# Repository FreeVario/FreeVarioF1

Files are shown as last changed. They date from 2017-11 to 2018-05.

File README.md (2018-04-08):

## Welcome to FreeVario

Freevario is an opensource device to provides telemetry data to any vario based program such as XCSoar or XCTrack via bluetooth or wifi. It is based on de STM32F3 processor. The project includes the board Eagle design and source code.
The current status of the project is beta, it is 100% usable, just some rough edges here and there. Since the paragliding season is active, only bug fixes will be added. 

  <p > 
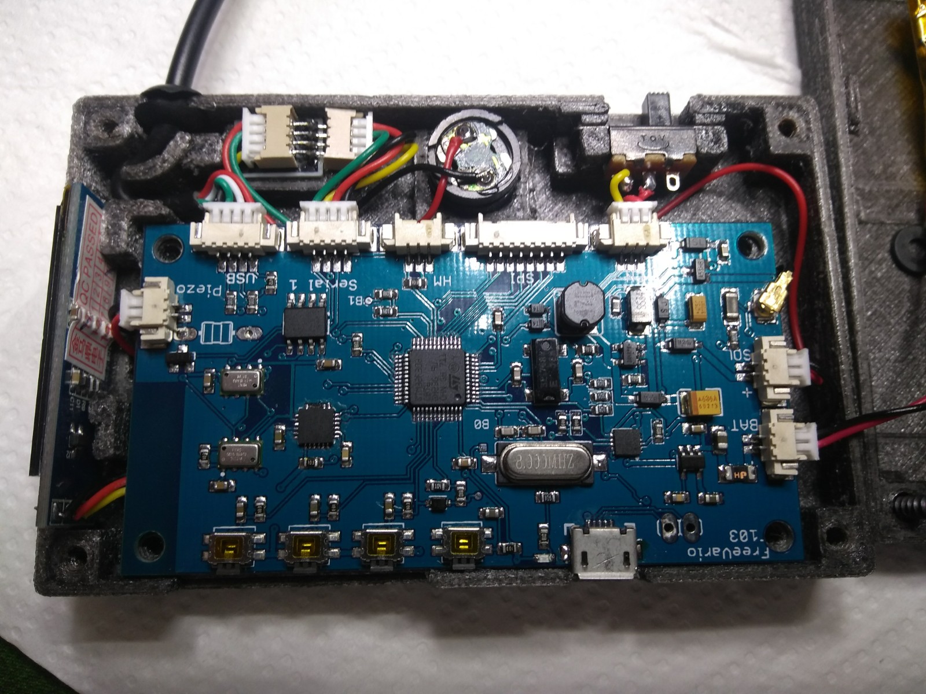
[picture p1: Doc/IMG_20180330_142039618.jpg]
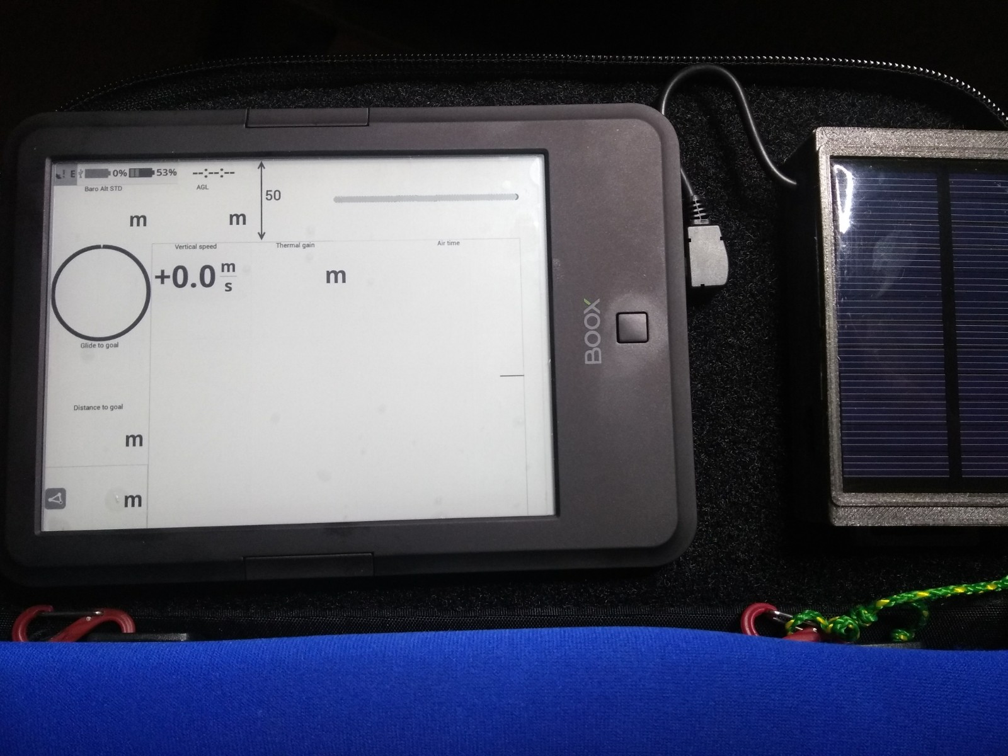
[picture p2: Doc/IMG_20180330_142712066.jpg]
     
  </p>
  <p > 
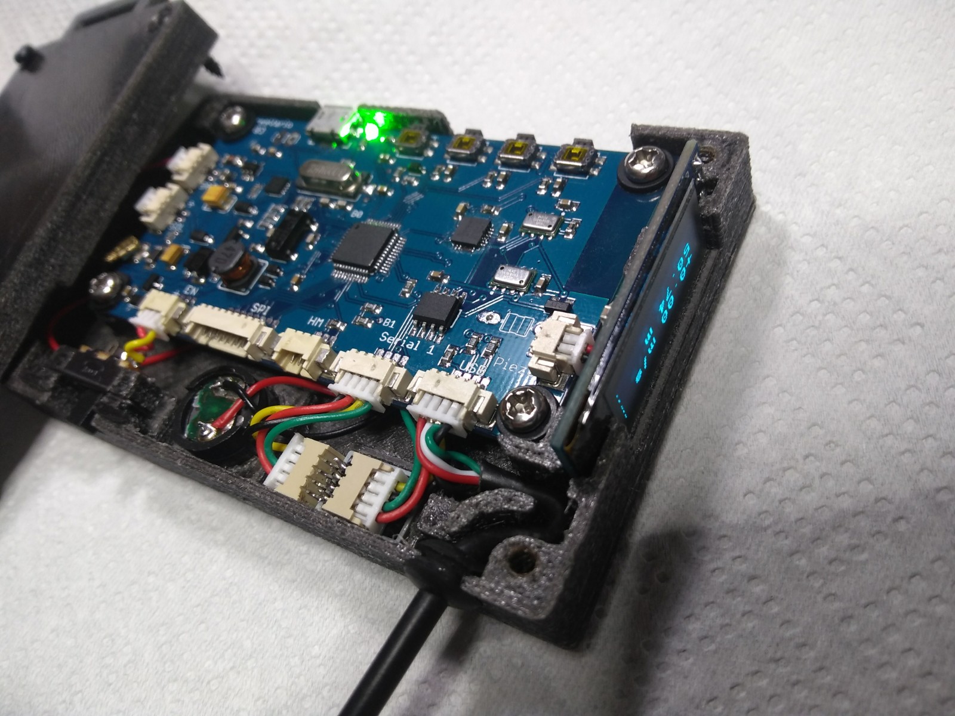
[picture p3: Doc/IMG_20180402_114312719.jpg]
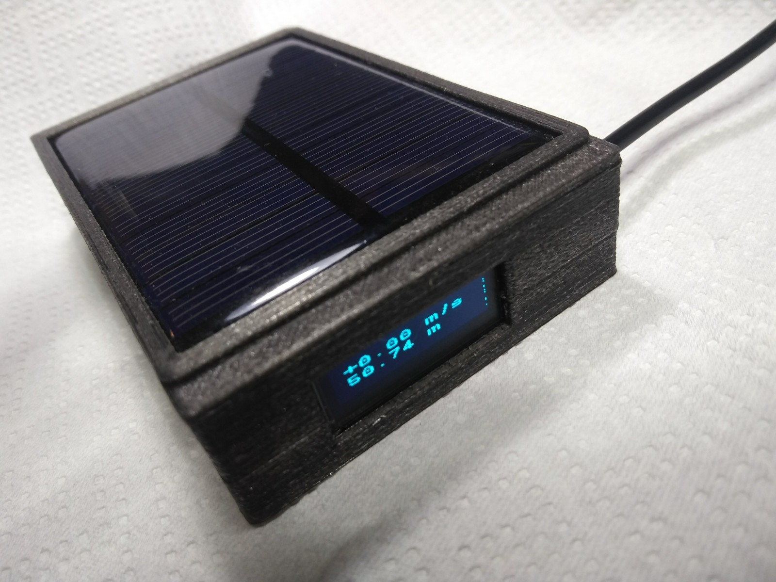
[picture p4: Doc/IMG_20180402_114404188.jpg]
     
  </p>

### Features:

Bluetooth, Serial or USB OTG streaming<br>
Solar charger <br>
Power bank (200mA) <br>
Power passthru from external supply <br>
Interval powerbank<br>
Dual pressure sensor support <br>
Adaptive Vario* <br>
Humidity sensor <br>
Accelerometer<br>
Piezo speaker for vario audio <br>
Serial GPS NMEA <br>
NMEA Output PCProbe, PTAS1 and LXNAV<br>

*Adaptive Vario: The sensitivity filter of the barometric sensors are adapted according to the environment. Eg. On a quiet day your flight will be more stable, causing the filter to become more sensitive to changes, this way you will be able to detect the lighter thermals.

#### Bluetooth, Serial or USB OTG streaming

Multiple options available. You can mount a HM-13 bluetooth module to stream BLE or standard bluetooth. Internal serial port can either be used for a i2c OLED display or as an internal serial port for built-in solutions like a Kobo reader.

#### Solar charger

The on board lipo charger can handle multiple power sources including a solar panel to extend the battery life.

#### Powerbank

A on board powerbank can supply up to 200mA 5V via the USB cable to any connected device. When the device is connected to a charger, it will activate a pass through circuit so that the connected device is also charged. This way, disconnecting the usb cable won’t be necessary.
Another option is interval power supply. This will deliver 1 minute out of 5 minutes to the connected device. Most devices won’t support this however. You will need a custom kernel for some Android devices. But is does work with Kobo devices and XCSoar (Top Hat) or LK8000.

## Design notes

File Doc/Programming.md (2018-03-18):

Programming the FreeVario V1 board

Requirements:
USB to serial
stm32flash program

Programming:

Connect the usb to serial adapter to Serial 1 on the board, but do not connect the
supply if it is not 3.3V. Use the USB to provide the supply.

Press and hold the next button and then the reset button.
Release the next button

Run: stm32flash -w FreeVario.binary -v -g 0x0 /dev/ttyUSB0 
(filename and USB may vary)

The board will reset

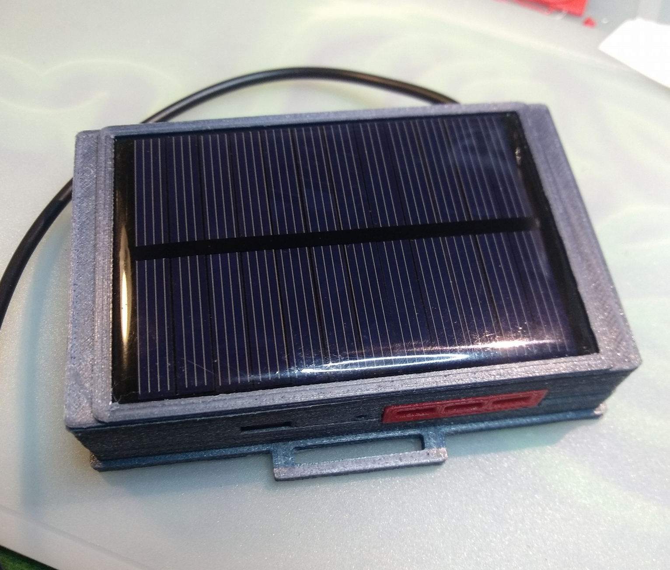
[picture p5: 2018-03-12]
Doc/freevario.png

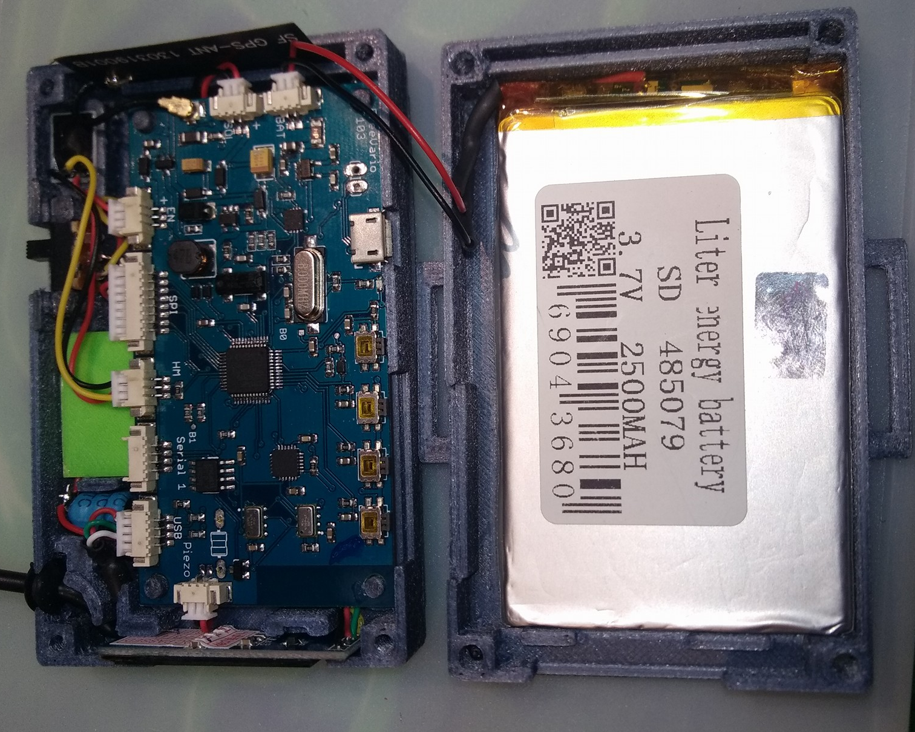
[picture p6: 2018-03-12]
Doc/freevarioinside.png

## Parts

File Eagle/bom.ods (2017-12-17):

 | Parts | Value | Device | Package | Description
1 | X1 | 2 pin | JST 1.25mm Connector SMD | 53261-02 | https://nl.aliexpress.com/item/10PCS-1-25mm-Connector-Horizontal-Type-Straight-Pin-Female-JST-Socket-2-3-4-5-6/32787273682.html
1 | X2 | 3-pin | JST 1.25mm Connector SMD | 53261-03
2 | X3, X4 | 4-pin | JST 1.25mm Connector SMD | 53261-04
1 | X5 | 8-pin | JST 1.25mm Connector SMD | 53261-08
1 | LED1 |  | LEDCHIP-LED0603 | CHIP-LED0603
0 | JP3 |  | Header pin | 1X02
1 | F1 |  | Self Reseting fuse 1A | R1206
4 | NEXT, OPTION, PREV, RESET |  | Push button | TS-015A | https://nl.aliexpress.com/item/100PCS-4-7x3-5x1-6mm-4-Pin-SMT-SMD-Side-Tact-Tactile-Push-Button-Switch-Mount/32699038907.html
1 | U1 |  | USB" | USB-MICRO-SMD | https://nl.aliexpress.com/item/IMC-Hot-20-Pcs-Micro-USB-Type-B-Female-Socket-180-Degree-5-Pin-SMD-SMT/32438682712.html
2 | R8, R9 | 100k | R-EU_R0603 | R0603
6 | C4, C10, C13, C20, C21, C23 | 104 | C-EUC0603K | C0603K
6 | C9, C2, C3, C15, C16 | 105 | C-EUC0603 | C0603
1 | C12 | 106 | C-EUC0603K | C0603K
9 | R10, R11, R12, R13, R14, R15, R16, R17, R18 | 10k | R-EU_R0603 | R0603
3 | R23, R24, R28 | 10k | RES-0603 | R0603
1 | C18 | 10uF | C-EUC0805 | C0805
4 | R1, R20, R21, R27 | 1M | R-0603 | 603
3 | D1, D2, D3 | 1N4148WS | DIODE-SOD323-R | SOD323-R
1 | D5 | 1N5817 | DIODESOD-123 | SOD-123
2 | D6, D4 | MBR0520LT1 | DIODESOD-123 | SOD-123
1 | D7 | 1N5822 | DIODE-DO-214AC | DO-214AC
4 | R2, R6, R7, R19 | 1k | R-EU_R0603 | R0603
1 | D8 | 1n5819 | DIODESOD-123 | SOD-123
1 | C14 | 2.2nf | C-EUC0603K | C0603K
2 | R3, R4 | 20R | R-EU_R0603 | R0603
4 | C5, C6, C7, C8 | 20p | C-EUC0603K | C0603K
1 | C11 | 223 | C-EUC0603K | C0603K
1 | R31 | 22R | R-EU_R0603 | R0603
1 | L1 | 22uH | SM-1206 | SM-1206
1 | R22 | 2k | RES-0603 | R0603
1 | R5 | 4.7k | R-EU_R0603 | R0603
1 | C17 | 4.7uF | 10UF-POLAR-EIA3216-16V Tantalum | EIA3216
1 | C1 | 470nf | C-EUC0603K | C0603K
1 | L2 | 47µH/±30%/750mA | INDUCTOR-CR54-47UH | CR54
2 | BAT, SOL | 53261-02 | JST 1.25mm Connector SMD | 53261-02
1 | X7 | 53261-03 | JST 1.25mm Connector SMD | 53261-03
1 | C26 | 68uF | CAP_POL3528 Tantalum | EIA3528
1 | Y1 | 8MHZ | CRYSTALSM49 | SM49
1 | U2 | AT24C1024B-8S1 | AT24C1024B-8S1 | SO08-8S1
1 | U3 | CN3065 | PMIC-CN3065-DFN8 | DFN-8
1 | HM13 | HM-11 | HM-19 Bluetooth 4.2 BLE | HM-11
1 | Y2 | 32.768 Khz | MC-306 | MC-306
1 | L4 | 10mH – 33mH | Optional Piezo booster | MMICC7
1 | AC1 | MPU-6050-1 | MPU-6050-1 | QFN-24-4MM2
2 | IC1, IC2 | MS5611-01BA03UNO | MS5611-01BA03UNO | SON125P300X500X100-8N
1 | U5 | NCP1402 | V_REG_NCP1400SOT23-5 | SOT23-5
1 | U4 | NEO-M8 | U-blox Neo GPS module | NEO-M8
1 | REG1 | RT9193-33 | MIC5219XX | SOT23-5
1 | Q2 | SI2305 | MOSFET-P'SI2323CDS/SI2305DS<BR>' | SOT-23
1 | Q1 | S8550 2TY | SMD-TRANSISTORS-PNP-25V-500MA(SOT-23) | SOT-23
1 | IC3 | STM32F10XCXT6 | STM32F10XCXT6 | TQFP48
0 | BOOT0, BOOT1 | TPTP08R | TPTP08R | TP08R
0 | TPVCC | TPTP08SQ | TPTP08SQ | TP08SQ
0 | J4 | U.FL-R-SMT(01) | YT2027 IPEX IPX | HRS_U.FL-R-SMT(01)
 | External
1 | Solar Panel 6V 0.6W 80*55MM
1 | 0.91 Inch 128x32 IIC I2C Blue OLED LCD Display Module
1 | 3mm DIY USB Cable
3 | JST 1.25mm 2p Male Plug with Wire
1 | JST 1.25mm 3p Male Plug with Wire
1 | JST 1.25mm 8p Male Plug with Wire
1 | JST 1.25mm 4p Male Plug & pin
1 | 3mm grommet
1 | 5 P Port Right Angle Micro USB Male Plug
1 | 3 Pin 2 Position Black Mini SPDT Slide Switches
1 | AM2322 digital temperature and humidity sensor
4 | M3 16mm self tapping screws
4 | M3 5mm self tapping screws
1 | 20mm Piezo Buzzer Disc Element
1 | Power Inductors 0406 4*6MM 33mH
1 | PS1003-1575 GPS1003 1575MHz. 4.3 dBi Multilayer Chip Antenna
 | GPS active antenna thin 12*17*2. 4mm ceramic

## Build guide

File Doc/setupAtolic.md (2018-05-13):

Short version:

Use STMCubeMx to create project using ioc file or generate a new one and
use the structure FreeVario/Src/FreeVario and name FreeVario

Open project in Atolic Studo

Use Team to create new Git repo and set the "In repository Folder" to /Src

Do a pull

Rightclick on project and select new-> Source Folder, select FreeVarioLib

Rightclick on added FreeVarioLib folder and select "Add/Remove include Path"

Open main.c
Add->
/* USER CODE BEGIN Includes */
#include "freevario.h"
/* USER CODE END Includes */

And->

  /* USER CODE BEGIN 2 */
  FV_Run();
  /* USER CODE END 2 */

Open usb_device.c

Add in void MX_USB_DEVICE_Init(void) -> 

  /* USER CODE BEGIN USB_DEVICE_Init_PreTreatment */
          //This will make a device think that the USB device has reconnected
          //Usefull for Android
	  GPIO_InitTypeDef GPIO_InitS;
	  GPIO_InitS.Pin = GPIO_PIN_12;
	  GPIO_InitS.Mode = GPIO_MODE_OUTPUT_PP;
	  GPIO_InitS.Pull = GPIO_NOPULL;
	  GPIO_InitS.Speed = GPIO_SPEED_FREQ_LOW;
	  HAL_GPIO_Init(GPIOA, &GPIO_InitS);
	  HAL_GPIO_WritePin(GPIOA,GPIO_PIN_12,GPIO_PIN_RESET);
	  HAL_Delay(300);
  /* USER CODE END USB_DEVICE_Init_PreTreatment */

Configure config_hal.h and config.h if needed
Build project 

Rules:

Only use the FreeVarioLib for development.
Do not include main.c, config_hal.h or config.h or any STM32 hal files

You have to add -u _printf_float to the c linker for Sprintf to work with floats
See: http://www.openstm32.org/forumthread954

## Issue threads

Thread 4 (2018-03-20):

Buzzer PWM polarity

FreeVario, 2018-03-20:
Make sure the  PWM is set to high when buzzer is muted.

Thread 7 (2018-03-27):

G-force not working

FreeVario, 2018-03-27:

FreeVario, 2018-03-30:
PCB Error . Pin 9 not connected. Possible to fix it by bridging with pin 8.

Closed 2018-03-30.

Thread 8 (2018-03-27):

OLED not working on STM32F303CBT6

FreeVario, 2018-03-27:
But works on the discovery board. Other devices does work on the same I2C bus

FreeVario, 2018-04-01:
fixed

Closed 2018-04-01.

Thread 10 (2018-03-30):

Add G-force Calibration

FreeVario, 2018-03-30:
Check #7 to fix mpu5050

FreeVario, 2018-03-30:
Value 10x higher. Must compensate for it.

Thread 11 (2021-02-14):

Info freevario

zetabeta87, 2021-02-14:
hi, I am a paraglider pilot and I am looking for a complete and accurate telemetry device to connect to an Android smartphone via cable or bluetooth and use it with xctrack or similar. The products on the market have a high cost and having desire to do, a basic electronic knowledge and ability to weld (but no programming knowledge) I thought I could find some projects online.
I saw that you have several projects about it and I wanted to ask you if you have a finished project of what I am looking for and if you would like to give me some indication on how to proceed in this regard I would be grateful.
Thanks a lot
Simone

primaldev, 2021-02-14:
Hi Simone, the latest version is this one: [https://github.com/FreeVario/FreeVario](url). But it does require a lot of knowledge regarding programming and hardware design. At this moment the best and easiest way to go is:[https://github.com/gereic/GXAirCom](url). It is a port from the SoftRF project but much easier to implement. I'm also looking at designing a custom board for it eventually.

zetabeta87, 2021-02-17:
Hi, thanks for your help. Is a good project for flarm but only with a base
GPS module.
I find this: https://github.com/prunkdump/arduino-variometer and the new
queston is:
with an Arduino pro micro, BT (or USB) module, GPS/glonass, a baro and
accellerometer sensor, It possibile send data to xctrack on an android
device via BT (or USB) and let him process it? Or it is much complicated
then this?
And maybe (for who knows how to program this) is possibile to implement it
with with flarm.
Thank you

Il dom 14 feb 2021, 16:17 primaldev <notifications@github.com> ha scritto:

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

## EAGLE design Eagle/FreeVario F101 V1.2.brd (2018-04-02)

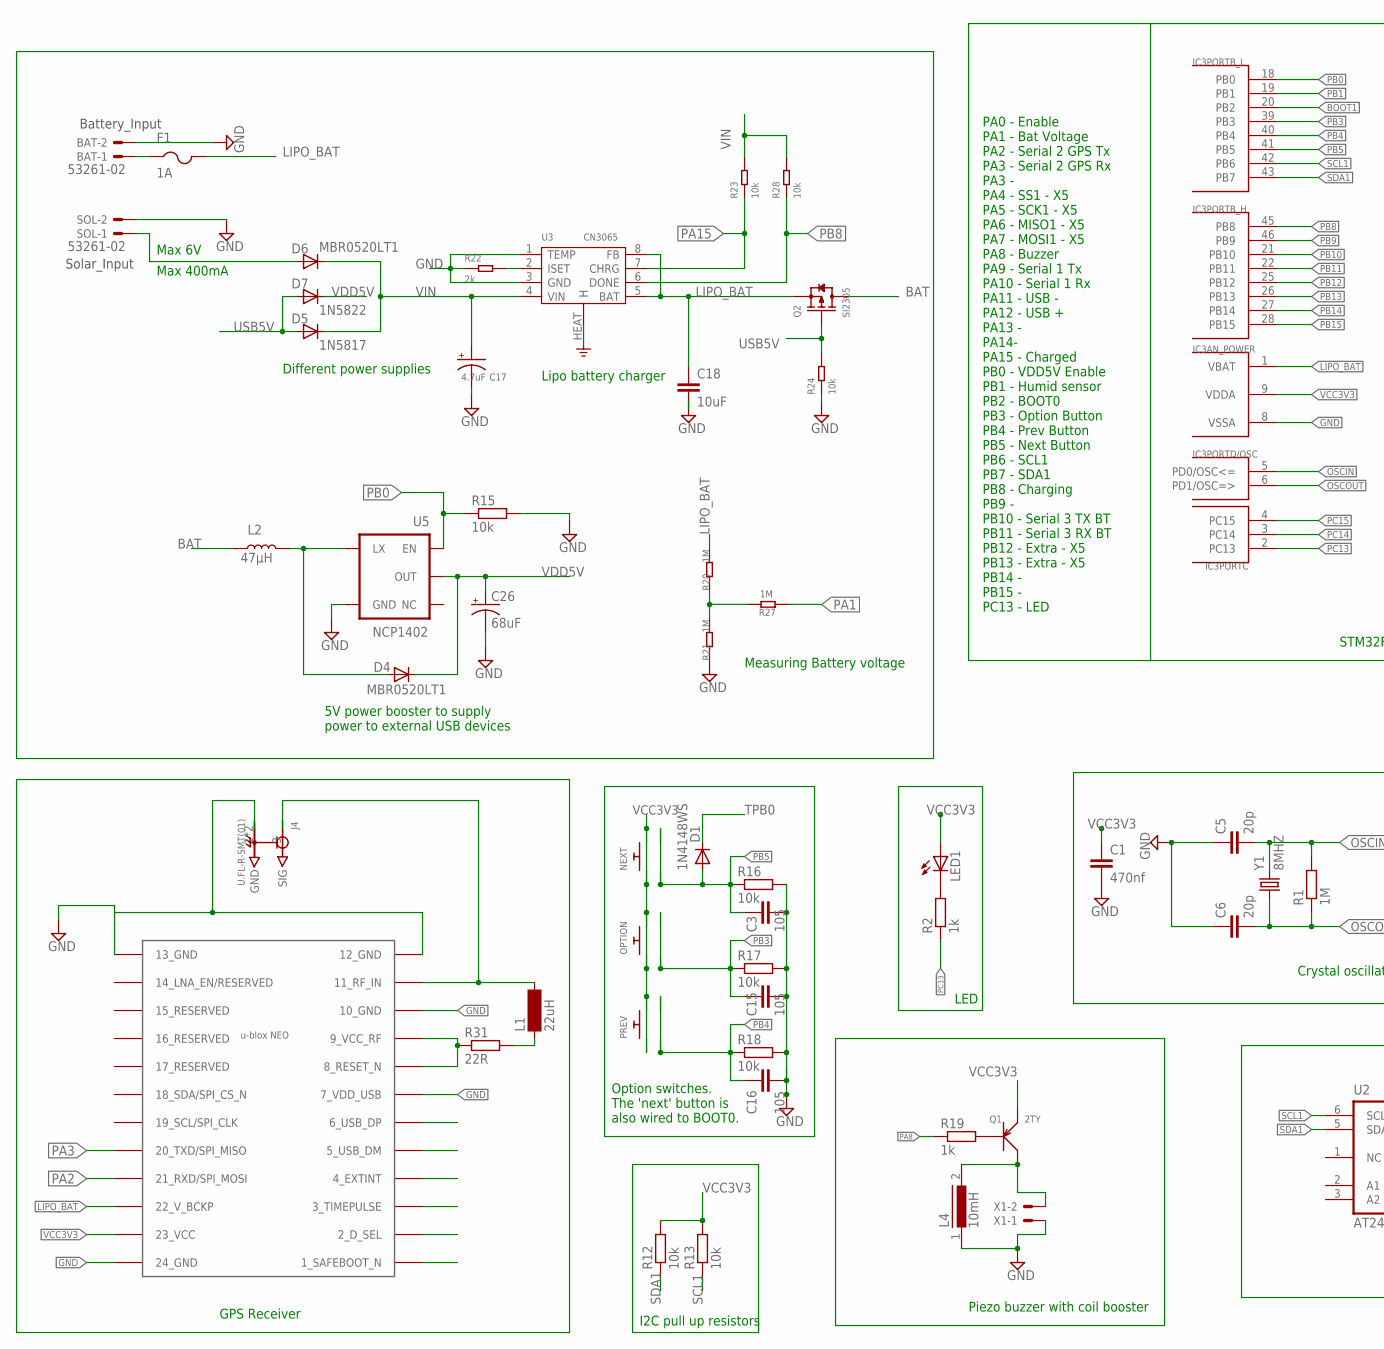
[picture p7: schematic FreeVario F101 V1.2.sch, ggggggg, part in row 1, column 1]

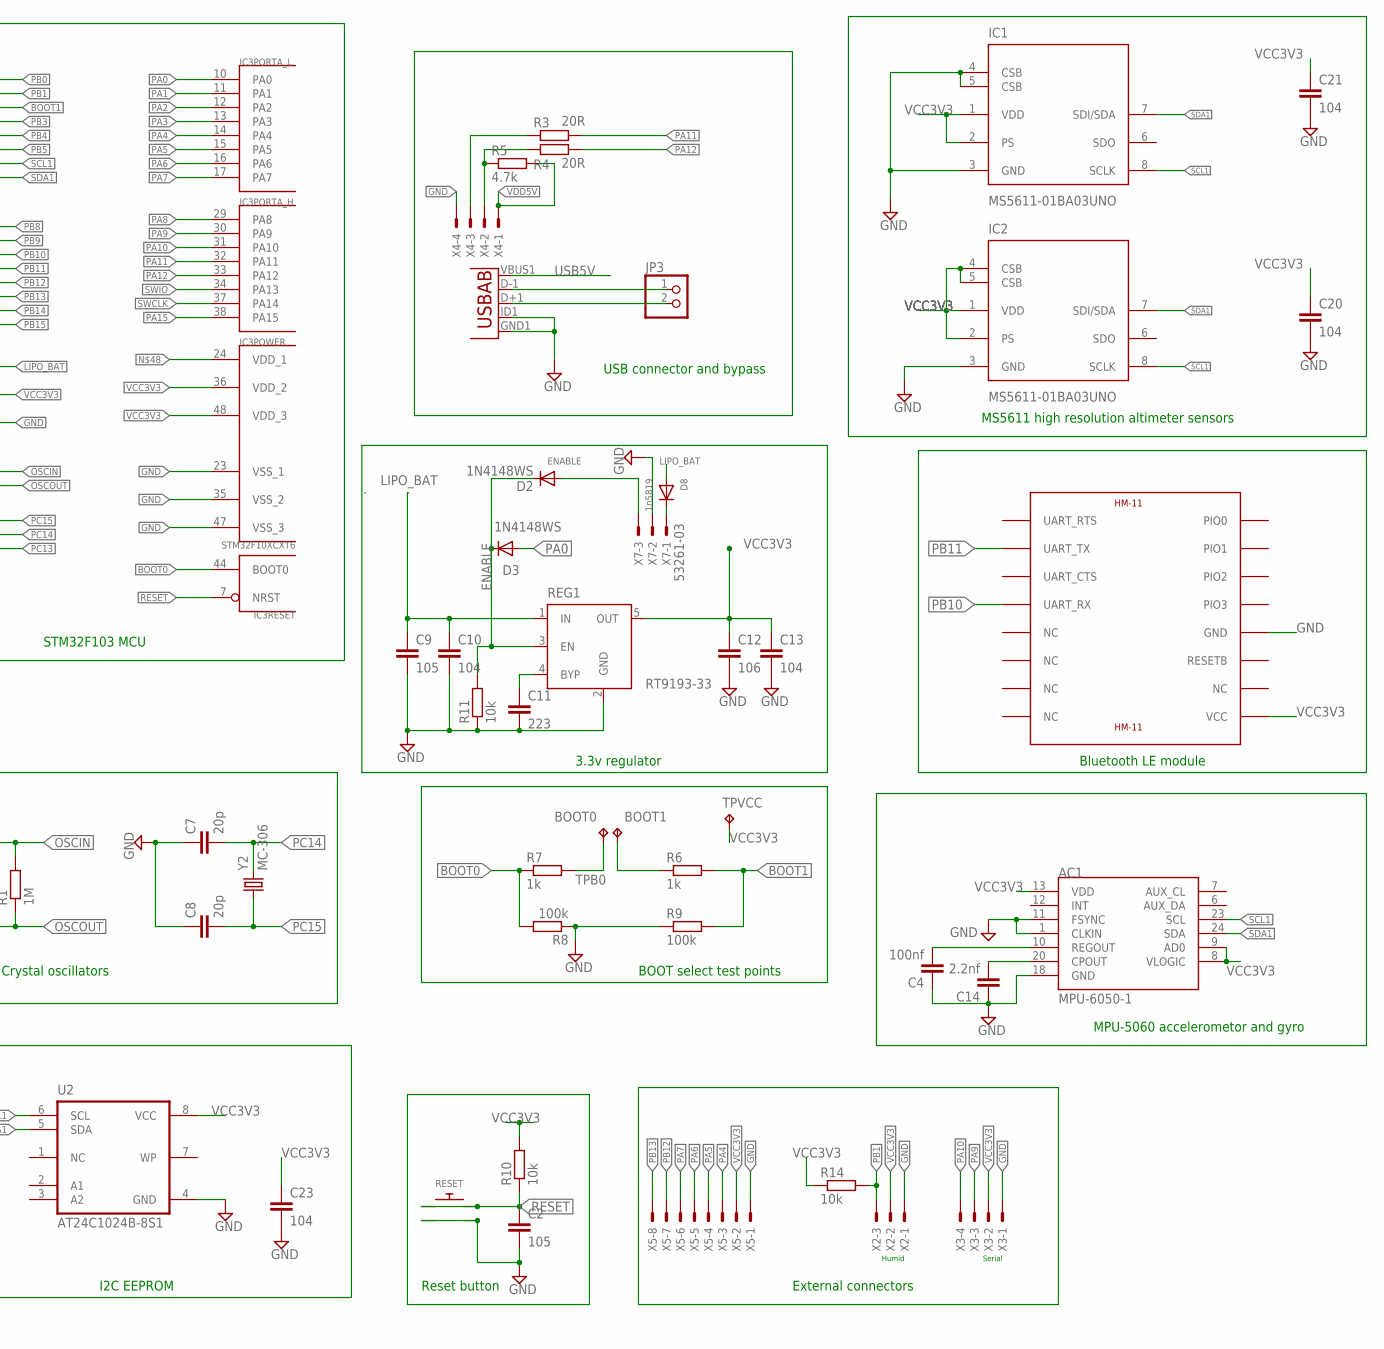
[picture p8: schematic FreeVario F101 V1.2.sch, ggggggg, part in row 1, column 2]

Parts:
AC1: MPU-6050-1; QFN-24-4MM2
BAT: 53261-02
BOOT0, BOOT1: TPTP08R; TP08R
C1: 470nf; C0603K
C2, C3, C15, C16: 105; C0603
C4: 100nf; C0603K
C5, C6, C7, C8: 20p; C0603K
C9: 105; C0603K
C10, C13, C20, C21, C23: 104; C0603K
C11: 223; C0603K
C12: 106; C0603K
C14: 2.2nf; C0603K
C17: 4.7uF; EIA3216
C18: 10uF; C0805
C26: 68uF; EIA3528
D1, D2, D3: 1N4148WS; SOD323-R
D4, D6: MBR0520LT1; SOD-123
D5: 1N5817; SOD-123
D7: 1N5822; DO-214AC
D8: 1n5819; SOD-123
F1: 1A; R1206
HM13: HM-11
IC1, IC2: MS5611-01BA03UNO; SON125P300X500X100-8N
IC3: STM32F10XCXT6; TQFP48
J4: U.FL-R-SMT(01); HRS_U.FL-R-SMT(01)
JP3: PINHD-1X2; 1X02
L1: 22uH; SM-1206
L2: 47µH; CR54
L4: 10mH; MMICC7
LED1: LEDCHIP-LED0603; CHIP-LED0603
NEXT: TS-015A
OPTION: TS-015A
PREV: TS-015A
Q1: 2TY; SOT-23
Q2: SI2305; SOT-23
R1: 1M; R0603
R2, R6, R7, R19: 1k; R0603
R3, R4: 20R; R0603
R5: 4.7k; R0603
R8, R9: 100k; R0603
R10, R11, R12, R13, R14, R15, R16, R17, R18, R23, R24, R28: 10k; R0603
R20, R21, R27: 1M; 0603
R22: 2k; R0603
R31: 22R; R0603
REG1: RT9193-33; SOT23-5
RESET: TS-015A
SOL: 53261-02
TPVCC: TPTP08SQ; TP08SQ
U1: USB""; USB-MICRO-SMD
U2: AT24C1024B-8S1; SO08-8S1
U3: CN3065; DFN-8
U4: NEO-M8
U5: NCP1402; SOT23-5
X1: 53261-02
X2, X7: 53261-03
X3, X4: 53261-04
X5: 53261-08
Y1: 8MHZ; SM49
Y2: MC-306

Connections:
BAT: L2.P$1 (1), Q2.3 (D)
BOOT0: IC3.44 (BOOT0), R7.1, R8.2
BOOT1: IC3.20 (PB2), R6.2, R9.2
ENABLE: D2.C, D3.C, R11.2, REG1.3 (EN)
GND: AC1.1 (CLKIN), AC1.11 (FSYNC), AC1.18 (GND), BAT.2, C1.2, C2.2, C3.2, C4.1, C5.1, C6.1, C7.1, C8.1, C9.2, C10.2, C11.2, C12.2, C13.2, C14.1, C15.2, C16.2, C17.-, C18.2, C20.2, C23.2, C26.C (-), HM13.GND, IC1.3 (GND), IC1.4 (CSB), IC1.5 (CSB), IC2.3 (GND), IC3.8 (VSSA), IC3.23 (VSS_1), IC3.35 (VSS_2), IC3.47 (VSS_3), J4.1 (GND), J4.2 (GND), L4.1, R8.1, R9.1, R11.1, R15.2, R16.2, R17.2, R18.2, R21.1, R22.1, R24.1, REG1.2 (GND), RESET.P$2, RESET.P$4, SOL.2, U1.GND1 (GND), U1.ID1 (USBID), U2.4 (GND), U3.1 (TEMP), U3.3 (GND), U3.HEAT (H), U4.7 (7_VDD_USB), U4.10 (10_GND), U4.12 (12_GND), U4.13 (13_GND), U4.24 (24_GND), U5.4 (GND), X1.1, X2.1, X3.1, X4.4, X5.1, X7.2
LIPO_BAT: C9.1, C10.1, C18.1, D8.A, F1.2, IC3.1 (VBAT), Q2.2 (S), R20.2, REG1.1 (IN), U3.5 (BAT), U3.8 (FB), U4.22 (22_V_BCKP)
unnamed: D8.C, X7.1
unnamed: LED1.C, R2.2
unnamed: C11.1, REG1.4 (BYP)
unnamed: R3.1, X4.3
unnamed: R4.1, R5.1, X4.2
unnamed: BAT.1, F1.1
unnamed: BOOT1.TP, R6.1
unnamed: R20.1, R21.2, R27.2
unnamed: D2.A, X7.3
unnamed: Q1.1 (B), R19.2
unnamed: D6.A, SOL.1
unnamed: AC1.10 (REGOUT), C4.2
unnamed: R22.2, U3.2 (ISET)
unnamed: AC1.20 (CPOUT), C14.2
unnamed: L4.2, Q1.3 (C), X1.2
unnamed: JP3.1, U1.D-1 (D-)
unnamed: JP3.2, U1.D+1 (D+)
unnamed: D4.A, L2.P$2 (2), U5.5 (LX)
unnamed: J4.3 (SIG), L1.2, U4.11 (11_RF_IN)
unnamed: L1.1, R31.2
unnamed: R31.1, U4.8 (8_RESET_N), U4.9 (9_VCC_RF)
OSCIN: C5.2, IC3.5 (PD0/OSC<=), R1.2, Y1.2
OSCOUT: C6.2, IC3.6 (PD1/OSC=>), R1.1, Y1.1
PA0: D3.A, IC3.10 (PA0)
PA1: IC3.11 (PA1), R27.1
PA2: IC3.12 (PA2), U4.21 (21_RXD/SPI_MOSI)
PA3: IC3.13 (PA3), U4.20 (20_TXD/SPI_MISO)
PA4: IC3.14 (PA4), X5.3
PA5: IC3.15 (PA5), X5.4
PA6: IC3.16 (PA6), X5.5
PA7: IC3.17 (PA7), X5.6
PA8: IC3.29 (PA8), R19.1
PA9: IC3.30 (PA9), X3.3
PA10: IC3.31 (PA10), X3.4
PA11: IC3.32 (PA11), R3.2
PA12: IC3.33 (PA12), R4.2
PA15: IC3.38 (PA15), R23.1, U3.7 (CHRG)
PB0: IC3.18 (PB0), R15.1, U5.1 (EN)
PB1: IC3.19 (PB1), R14.2, X2.3
PB3: C15.1, IC3.39 (PB3), OPTION.P$2, OPTION.P$4, R17.1
PB4: C16.1, IC3.40 (PB4), PREV.P$2, PREV.P$4, R18.1
PB5: C3.1, D1.A, IC3.41 (PB5), NEXT.P$2, NEXT.P$4, R16.1
PB8: IC3.45 (PB8), R28.1, U3.6 (DONE)
PB9: IC3.46 (PB9)
PB10: HM13.UART_RX, IC3.21 (PB10)
PB11: HM13.UART_TX, IC3.22 (PB11)
PB12: IC3.25 (PB12), X5.7
PB13: IC3.26 (PB13), X5.8
PB14: IC3.27 (PB14)
PB15: IC3.28 (PB15)
PC13: IC3.2 (PC13), R2.1
PC14: C7.2, IC3.3 (PC14), Y2.4 (2)
PC15: C8.2, IC3.4 (PC15), Y2.1
RESET: C2.1, IC3.7 (NRST), R10.1, RESET.P$1, RESET.P$3
SCL1: AC1.23 (SCL), IC1.8 (SCLK), IC2.8 (SCLK), IC3.42 (PB6), R13.1, U2.6 (SCL)
SDA1: AC1.24 (SDA), IC1.7 (SDI/SDA), IC2.7 (SDI/SDA), IC3.43 (PB7), R12.1, U2.5 (SDA)
SWCLK: IC3.37 (PA14)
SWIO: IC3.34 (PA13)
TPB0: BOOT0.TP, D1.C, R7.2
USB5V: D5.A, D7.A, Q2.1 (G), R24.2, U1.VBUS1 (VBUS)
VCC3V3: AC1.8 (VLOGIC), AC1.9 (AD0), AC1.13 (VDD), C1.1, C12.1, C13.1, C20.1, C21.1, C23.1, HM13.VCC, IC1.1 (VDD), IC1.2 (PS), IC2.1 (VDD), IC2.2 (PS), IC2.4 (CSB), IC2.5 (CSB), IC3.9 (VDDA), IC3.36 (VDD_2), IC3.48 (VDD_3), LED1.A, NEXT.P$1, NEXT.P$3, OPTION.P$1, OPTION.P$3, PREV.P$1, PREV.P$3, Q1.2 (E), R10.2, R12.2, R13.2, R14.1, REG1.5 (OUT), TPVCC.TP, U2.8 (VCC), U4.23 (23_VCC), X2.2, X3.2, X5.2
VDD5V: C26.A (+), D4.C, D7.C, R5.2, U5.2 (OUT), X4.1
VIN: C17.+, D5.C, D6.C, R23.2, R28.2, U3.4 (VIN)

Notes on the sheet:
Serial
Humid
Solar_Input
Battery_Input
PA0 - Enable PA1 - Bat Voltage PA2 - Serial 2 GPS Tx PA3 - Serial 2 GPS Rx PA3 - PA4 - SS1 - X5 PA5 - SCK1 - X5 PA6 - MISO1 - X5 PA7 - MOSI1 - X5 PA8 - Buzzer PA9 - Serial 1 Tx PA10 - Serial 1 Rx PA11 - USB - PA12 - USB + PA13 - PA14- PA15 - Charged PB0 - VDD5V Enable PB1 - Humid sensor PB2 - BOOT0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
Max 400mA
Measuring Battery voltage
5V power booster to supply power to external USB devices
Lipo battery charger
Different power supplies
Max 6V
GPS Receiver
Crystal oscillators
Piezo buzzer with coil booster
External connectors
STM32F103 MCU
Reset button
I2C pull up resistors
Option switches. The 'next' button is also wired to BOOT0.
MS5611 high resolution altimeter sensors
Bluetooth LE module
MPU-5060 accelerometor and gyro
I2C EEPROM
BOOT select test points
3.3v regulator
USB connector and bypass
LED

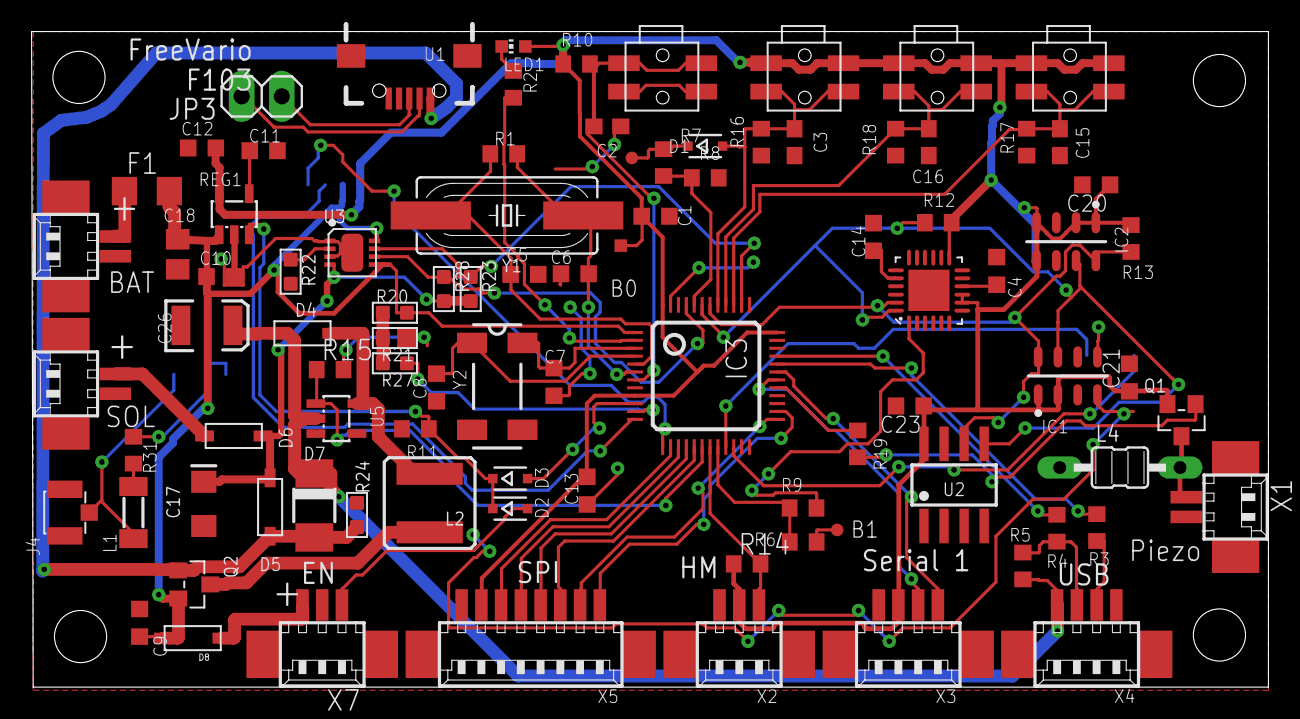
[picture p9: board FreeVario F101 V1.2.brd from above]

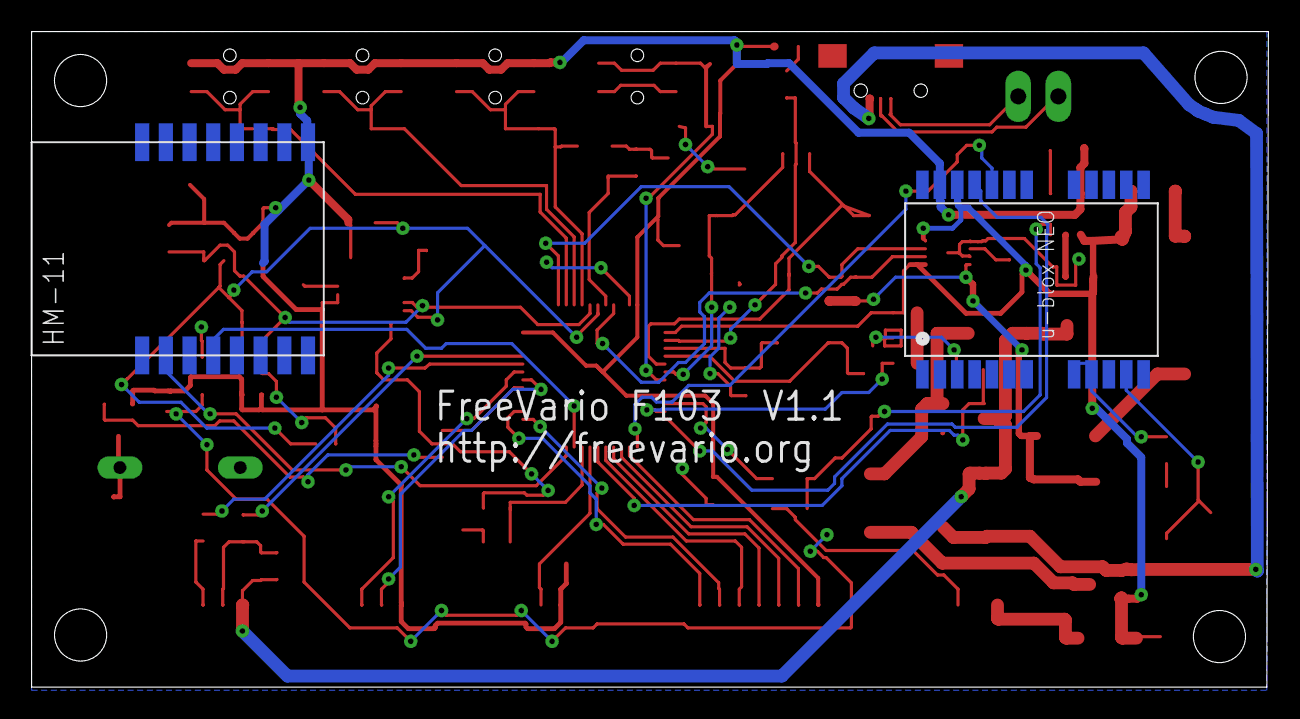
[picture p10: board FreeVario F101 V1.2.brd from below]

Board: 2 copper layers, 78.3 x 41.5 mm, 98 parts (2 on the bottom side), 64 nets.

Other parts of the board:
U$1, U$2, U$3, U$4: STAND-OFF

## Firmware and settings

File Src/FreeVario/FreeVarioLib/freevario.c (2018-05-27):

/*
 FreeVario http://FreeVario.org

  Copyright (c), PrimalCode (http://www.primalcode.org)
  This program is free software: you can redistribute it and/or modify
  it under the terms of the GNU General Public License as published by
  the Free Software Foundation, either version 3 of the License, or
  any later version. see <http://www.gnu.org/licenses/>
*/

#include "freevario.h"
#include "audio.h"
#include "barosensor.h"
#include "accelerometer.h"
#include "humidity.h"
#include "senddata.h"
#include "display.h"
#include "buttons.h"
#include "boardgpio.h"
#include <string.h>
#include <stdio.h>

#define GPSDMABUFFER 128

uint8_t  receiveBuffer[GPSDMABUFFER*2];
uint8_t  transferBuffer[GPSDMABUFFER];

uint32_t sc_timer=0;
uint32_t sc_timer100=0;
uint32_t sc_timer1000=0;
uint32_t sc_timer200=0;
uint8_t startwaitcomplete=0;
uint32_t startTime=0;
volatile uint8_t gpsdata=0;
uint8_t sensorToken = 0;
uint8_t dataValid=1;
uint8_t hasrunonce=0;

#ifdef FV_UARTGPS
void HAL_UART_RxCpltCallback(UART_HandleTypeDef *UartHandle)
{
	memcpy(&transferBuffer, &receiveBuffer, sizeof( receiveBuffer));

	gpsdata =1;
}

void HAL_UART_DMARxHalfCplt(UART_HandleTypeDef *UartHandle)
{
	memcpy(&transferBuffer, &receiveBuffer, sizeof( receiveBuffer));

	gpsdata =1;
}
#endif

//Called from main.c
void FV_Run(){
	setup();
	while(1){
		loop();
	}
}

//fast loop
void run10() {
#ifdef FV_BRNPRT
	BTN_Read();
#endif
	sensorToken++;
	switch(sensorToken) {
	case 1:
#ifdef VARIO
		Baro_Read();
#endif
		break;
	case 2:
#ifdef ACCL
		ACCL_Read();
#endif
		break;
	case 3:
#ifdef BUZZER
		if (takeoff) makeVarioAudio((float)currentVarioMPS);
#endif
		break;
	}
	if (sensorToken >= 3) {
		sensorToken = 0;
	}
}


void run100() {

	calcVario();
	if (startwaitcomplete && dataValid) {
		checkAdaptiveVario(currentVarioMPS);

	}

}
//sendata loop
void run200() {
	if (startwaitcomplete && dataValid) {
		sendSensorData();
	}

}

//slow loop
void run1000() {
	if (startwaitcomplete && dataValid) {
#ifdef BGPIO
		BGPIO_Read(); //must happen before display update and per second
#endif
#ifdef FV_OLEDI2C
		DISP_Update();
#endif
	}
#if defined(HUMID)
	HUMID_Read();
#endif
#if defined(TESTBUZZER)
			AUDIO_TestToneCall();
#endif
#ifdef FV_LED
			HAL_GPIO_TogglePin(FV_LED_GPIO, FV_LED);
#endif
}

/*
 *
 * Onetime run after startwait completed
 */

void runOnce(){
#ifdef BUZZERSTARTUPSOUND
	resetTone();
#endif

#ifdef FV_OTGENABLEPIN
	HAL_GPIO_WritePin(FV_OTGENABLEPORT,FV_OTGENABLEPIN,GPIO_PIN_RESET);
#endif

}


void setup() {

#if defined FV_OTGENABLEPIN && defined NOOTGDELAY
	if (HAL_GPIO_ReadPin(FV_BRNPRT, FV_BTNOPTION) == GPIO_PIN_RESET) {
		HAL_GPIO_WritePin(FV_OTGENABLEPORT,FV_OTGENABLEPIN,GPIO_PIN_RESET);

	}
#endif
#ifdef FV_UARTGPS
	HAL_UART_Receive_DMA(&FV_UARTGPS, (uint8_t *)receiveBuffer, GPSDMABUFFER);
#endif
#ifdef BGPIO
	BGPIO_Setup();
#endif
	setupSendData();
#ifdef FV_OLEDI2C
	DISP_Setup();
	DISP_SetMode(DISPPOWERDATA);
	showStartUP();
#endif

	setupConfig();

#ifdef BUZZER
	AUDIO_Setup_Tone();
#ifdef BUZZERSTARTUPSOUND
		StartupTone();
#endif
#endif

#ifdef VARIO
	BARO_Setup();
#endif
#ifdef ACCL
	ACCL_Setup();
#endif
#ifdef HUMID
	HUMID_Setup();
#endif
	HAL_Delay(100);
	startTime = HAL_GetTick();



}

void loop() {

	if(gpsdata) {
		gpsdata=0;

		for (uint8_t i = 0; i < GPSDMABUFFER; ++i) {
				SendDataGPSbuid( &transferBuffer[i]);
		}
	}


	if ((HAL_GetTick() - startTime) > STARTDELAY) {
		startwaitcomplete = true;
		if (!hasrunonce) {
			runOnce();
			hasrunonce=1;
		}

	}

	if (HAL_GetTick() >= (sc_timer + 10)) {
		sc_timer = HAL_GetTick();
		run10();

	}
//Do not change this value, it is used to calculate m/s
	if (HAL_GetTick() >= (sc_timer100 + 100)) {
		sc_timer100 = HAL_GetTick();
		run100();

	}


	if (HAL_GetTick() >= (sc_timer200 + 200)) {
		sc_timer200 = HAL_GetTick();
		run200();

	}

	if (HAL_GetTick() >= (sc_timer1000 + 1000)) {
		sc_timer1000 = HAL_GetTick();
		run1000();

	}


#if defined(TAKEOFFVARIO) && !defined(TESTBUZZER)
	if ((HAL_GetTick() - startTime) > (STARTDELAY + 4000) && !takeoff) {
		if (fabs(currentVarioMPS) > (float) TAKEOFFVARIO) {
			takeoff = true;
		}

	}
#else
	takeoff = true;
#endif
#ifdef FV_IWDG
		HAL_IWDG_Refresh ( &FV_IWDG ) ;
#endif


}

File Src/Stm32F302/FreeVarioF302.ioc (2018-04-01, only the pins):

Mcu.UserName=STM32F302CBTx
PA10.Signal=I2C2_SDA
PA11.Signal=USB_DM
PA12.Signal=USB_DP
PA15.Signal=GPIO_Input
PA2.Signal=USART2_TX
PA3.Signal=USART2_RX
PA4.Signal=COMP_DAC1_group
PA8.Signal=S_TIM1_CH1
PA9.Signal=I2C2_SCL
PB0.Signal=GPIO_Output
PB10.Signal=USART3_TX
PB11.Signal=USART3_RX
PB3.Signal=GPXTI3
PB4.Signal=GPXTI4
PB5.Signal=GPXTI5
PB6.Signal=I2C1_SCL
PB7.Signal=I2C1_SDA
PB8.Signal=GPIO_Input
PC13.Signal=GPIO_Output
PC14-OSC32_IN.Signal=RCC_OSC32_IN
PC15-OSC32_OUT.Signal=RCC_OSC32_OUT
PF0-OSC_IN.Signal=RCC_OSC_IN
PF1-OSC_OUT.Signal=RCC_OSC_OUT

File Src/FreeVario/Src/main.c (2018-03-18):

/**
  ******************************************************************************
  * File Name          : main.c
  * Description        : Main program body
  ******************************************************************************
  * This notice applies to any and all portions of this file
  * that are not between comment pairs USER CODE BEGIN and
  * USER CODE END. Other portions of this file, whether 
  * inserted by the user or by software development tools
  * are owned by their respective copyright owners.
  *
  * Copyright (c) 2018 STMicroelectronics International N.V. 
  * All rights reserved.
  *
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
  ******************************************************************************
  */

/* Includes ------------------------------------------------------------------*/
#include "main.h"
#include "stm32f3xx_hal.h"
#include "usb_device.h"

/* USER CODE BEGIN Includes */
#include "freevario.h"
/* USER CODE END Includes */

ADC_HandleTypeDef hadc1;

DAC_HandleTypeDef hdac;
DMA_HandleTypeDef hdma_dac_ch1;

I2C_HandleTypeDef hi2c1;
I2C_HandleTypeDef hi2c2;

IWDG_HandleTypeDef hiwdg;

TIM_HandleTypeDef htim1;
TIM_HandleTypeDef htim3;
TIM_HandleTypeDef htim6;

UART_HandleTypeDef huart2;
UART_HandleTypeDef huart3;
DMA_HandleTypeDef hdma_usart2_rx;

/* USER CODE BEGIN PV */

/* USER CODE END PV */

void SystemClock_Config(void);
static void MX_GPIO_Init(void);
static void MX_DMA_Init(void);
static void MX_I2C1_Init(void);
static void MX_I2C2_Init(void);
static void MX_USART2_UART_Init(void);
static void MX_TIM1_Init(void);
static void MX_TIM3_Init(void);
static void MX_USART3_UART_Init(void);
static void MX_DAC_Init(void);
static void MX_TIM6_Init(void);
static void MX_IWDG_Init(void);
static void MX_ADC1_Init(void);

void HAL_TIM_MspPostInit(TIM_HandleTypeDef *htim);
                                

/* USER CODE BEGIN PFP */

/* USER CODE END PFP */

int main(void)
{

  /* MCU Configuration----------------------------------------------------------*/

  /* Reset of all peripherals, Initializes the Flash interface and the Systick. */
  HAL_Init();

  /* Configure the system clock */
  SystemClock_Config();

  /* Initialize all configured peripherals */
  MX_GPIO_Init();
  MX_DMA_Init();
  MX_I2C1_Init();
  MX_I2C2_Init();
  MX_USB_DEVICE_Init();
  MX_USART2_UART_Init();
  MX_TIM1_Init();
  MX_TIM3_Init();
  MX_USART3_UART_Init();
  MX_DAC_Init();
  MX_TIM6_Init();
  MX_IWDG_Init();
  MX_ADC1_Init();

  /* USER CODE BEGIN 2 */

  FV_Run();
  /* USER CODE END 2 */

  /* Infinite loop */
  /* USER CODE BEGIN WHILE */
  while (1)
  {
  /* USER CODE END WHILE */

  /* USER CODE BEGIN 3 */

  }
  /* USER CODE END 3 */

}

/** System Clock Configuration
*/
void SystemClock_Config(void)
{

  RCC_OscInitTypeDef RCC_OscInitStruct;
  RCC_ClkInitTypeDef RCC_ClkInitStruct;
  RCC_PeriphCLKInitTypeDef PeriphClkInit;

    /**Initializes the CPU, AHB and APB busses clocks 
    */
  RCC_OscInitStruct.OscillatorType = RCC_OSCILLATORTYPE_LSI|RCC_OSCILLATORTYPE_HSE;
  RCC_OscInitStruct.HSEState = RCC_HSE_BYPASS;
  RCC_OscInitStruct.HSEPredivValue = RCC_HSE_PREDIV_DIV1;
  RCC_OscInitStruct.HSIState = RCC_HSI_ON;
  RCC_OscInitStruct.LSIState = RCC_LSI_ON;
  RCC_OscInitStruct.PLL.PLLState = RCC_PLL_ON;
  RCC_OscInitStruct.PLL.PLLSource = RCC_PLLSOURCE_HSE;
  RCC_OscInitStruct.PLL.PLLMUL = RCC_PLL_MUL6;
  if (HAL_RCC_OscConfig(&RCC_OscInitStruct) != HAL_OK)
  {
    _Error_Handler(__FILE__, __LINE__);
  }

    /**Initializes the CPU, AHB and APB busses clocks 
    */
  RCC_ClkInitStruct.ClockType = RCC_CLOCKTYPE_HCLK|RCC_CLOCKTYPE_SYSCLK
                              |RCC_CLOCKTYPE_PCLK1|RCC_CLOCKTYPE_PCLK2;
  RCC_ClkInitStruct.SYSCLKSource = RCC_SYSCLKSOURCE_PLLCLK;
  RCC_ClkInitStruct.AHBCLKDivider = RCC_SYSCLK_DIV1;
  RCC_ClkInitStruct.APB1CLKDivider = RCC_HCLK_DIV2;
  RCC_ClkInitStruct.APB2CLKDivider = RCC_HCLK_DIV1;

  if (HAL_RCC_ClockConfig(&RCC_ClkInitStruct, FLASH_LATENCY_1) != HAL_OK)
  {
    _Error_Handler(__FILE__, __LINE__);
  }

  PeriphClkInit.PeriphClockSelection = RCC_PERIPHCLK_USB|RCC_PERIPHCLK_USART2
                              |RCC_PERIPHCLK_USART3|RCC_PERIPHCLK_I2C1
                              |RCC_PERIPHCLK_I2C2|RCC_PERIPHCLK_TIM1
                              |RCC_PERIPHCLK_ADC12;
  PeriphClkInit.Usart2ClockSelection = RCC_USART2CLKSOURCE_PCLK1;
  PeriphClkInit.Usart3ClockSelection = RCC_USART3CLKSOURCE_PCLK1;
  PeriphClkInit.Adc12ClockSelection = RCC_ADC12PLLCLK_DIV1;
  PeriphClkInit.I2c1ClockSelection = RCC_I2C1CLKSOURCE_SYSCLK;
  PeriphClkInit.I2c2ClockSelection = RCC_I2C2CLKSOURCE_SYSCLK;
  PeriphClkInit.USBClockSelection = RCC_USBCLKSOURCE_PLL;
  PeriphClkInit.Tim1ClockSelection = RCC_TIM1CLK_HCLK;
  if (HAL_RCCEx_PeriphCLKConfig(&PeriphClkInit) != HAL_OK)
  {
    _Error_Handler(__FILE__, __LINE__);
  }

    /**Configure the Systick interrupt time 
    */
  HAL_SYSTICK_Config(HAL_RCC_GetHCLKFreq()/1000);

    /**Configure the Systick 
    */
  HAL_SYSTICK_CLKSourceConfig(SYSTICK_CLKSOURCE_HCLK);

  /* SysTick_IRQn interrupt configuration */
  HAL_NVIC_SetPriority(SysTick_IRQn, 0, 0);
}

/* ADC1 init function */
static void MX_ADC1_Init(void)
{

  ADC_MultiModeTypeDef multimode;
  ADC_ChannelConfTypeDef sConfig;

    /**Common config 
    */
  hadc1.Instance = ADC1;
  hadc1.Init.ClockPrescaler = ADC_CLOCK_ASYNC_DIV1;
  hadc1.Init.Resolution = ADC_RESOLUTION_12B;
  hadc1.Init.ScanConvMode = ADC_SCAN_DISABLE;
  hadc1.Init.ContinuousConvMode = ENABLE;
  hadc1.Init.DiscontinuousConvMode = DISABLE;
  hadc1.Init.ExternalTrigConvEdge = ADC_EXTERNALTRIGCONVEDGE_NONE;
  hadc1.Init.ExternalTrigConv = ADC_SOFTWARE_START;
  hadc1.Init.DataAlign = ADC_DATAALIGN_RIGHT;
  hadc1.Init.NbrOfConversion = 1;
  hadc1.Init.DMAContinuousRequests = DISABLE;
  hadc1.Init.EOCSelection = ADC_EOC_SINGLE_CONV;
  hadc1.Init.LowPowerAutoWait = DISABLE;
  hadc1.Init.Overrun = ADC_OVR_DATA_OVERWRITTEN;
  if (HAL_ADC_Init(&hadc1) != HAL_OK)
  {
    _Error_Handler(__FILE__, __LINE__);
  }

    /**Configure the ADC multi-mode 
    */
  multimode.Mode = ADC_MODE_INDEPENDENT;
  if (HAL_ADCEx_MultiModeConfigChannel(&hadc1, &multimode) != HAL_OK)
  {
    _Error_Handler(__FILE__, __LINE__);
  }

    /**Configure Regular Channel 
    */
  sConfig.Channel = ADC_CHANNEL_VBAT;
  sConfig.Rank = 1;
  sConfig.SingleDiff = ADC_SINGLE_ENDED;
  sConfig.SamplingTime = ADC_SAMPLETIME_1CYCLE_5;
  sConfig.OffsetNumber = ADC_OFFSET_NONE;
  sConfig.Offset = 0;
  if (HAL_ADC_ConfigChannel(&hadc1, &sConfig) != HAL_OK)
  {
    _Error_Handler(__FILE__, __LINE__);
  }

}
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

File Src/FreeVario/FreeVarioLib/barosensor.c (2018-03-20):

/*
 FreeVario http://FreeVario.org

  Copyright (c), PrimalCode (http://www.primalcode.org)
  This program is free software: you can redistribute it and/or modify
  it under the terms of the GNU General Public License as published by
  the Free Software Foundation, either version 3 of the License, or
  any later version. see <http://www.gnu.org/licenses/>
*/

#include "barosensor.h"
#include "stackops.h"
#include <math.h>

extern int32_t realPressureAv; // pressure hpa * 100

extern float currentVarioMPS; //
extern float cuttentVarioAvMPS;
extern float currentAltitudeMtr;
extern uint8_t dataValid;
uint8_t takeoff=0;
extern uint8_t startwaitcomplete;
uint8_t vTriggerd;
Queue_t VarioMPS;
Queue_t AltitudeMtr;
uint32_t vtime=0;
int16_t count=0;
uint32_t rtime=0;
uint32_t berrors=0;
int32_t rawPressurePrev = 0; //previous direct reading
int32_t rawPressurePrev2 = 0;

SD_MS5611 baro1;
#if defined(VARIO2)
SD_MS5611 baro2;
#endif




void BARO_Setup(){

	baro1.i2chelper.instance = &FV_I2C1;
	baro1.i2chelper.sclPin = FV_I2C1_SCL_Pin;
	baro1.i2chelper.sdaPin = FV_I2C1_SDA_Pin;
    baro1.i2chelper.i2cPort = FV_I2CI_PORT;
	MS5611_Setup( &baro1, MS5611_ADD1);

#if defined(VARIO2)
	baro2.i2chelper.instance = &FV_I2C1;
	baro2.i2chelper.sclPin = FV_I2C1_SCL_Pin;
	baro2.i2chelper.sdaPin = FV_I2C1_SDA_Pin;
    baro2.i2chelper.i2cPort = FV_I2CI_PORT;
	MS5611_Setup(  &baro2, MS5611_ADD2);
#endif
	SO_setQueue(&VarioMPS, 10); //vario m/s
	SO_setQueue(&AltitudeMtr, 10); //alitude in meters
}

void BARO_Reset(){

	if (HAL_GetTick() - rtime >= 15000) { //prevents reset loop
		MS5611_Reset(&baro1);
#if defined(VARIO2)
		MS5611_Reset(&baro2);
#endif
		BARO_Setup();
		rtime = HAL_GetTick();
	}

}


float getAltitudeFt() {

	return getAltitudeMt() * 145366.45;

}

float getAltitudeMt() {

	return 44330.0f * (1.0f - pow(realPressureAv / (float)conf.qnePressure, 0.1902949f));


}

//This must be called at 100ms
void calcVario() {

    currentAltitudeMtr = getAltitudeMt();

    SO_enqueue(&AltitudeMtr, currentAltitudeMtr);


    count=0;//Debug counter.
    if (SO_qisFull(&AltitudeMtr)) {
        currentVarioMPS =  SO_rear(&AltitudeMtr) -  SO_front(&AltitudeMtr);
        cuttentVarioAvMPS = SO_getAvarage(&VarioMPS);
    }else{
        currentVarioMPS = 0;
    }


}
//Check for erratic values
uint32_t getCleanValues(SD_MS5611  baro) {
	uint32_t pressure = 0;

	if (startwaitcomplete) {
		if (fabs(realPressureAv - baro.uP) < 5000) {
			pressure = baro.uP;
			berrors = 0;
		} else { //invalid data
			I2C_ClearBusyFlagErratum(&baro.i2chelper, 1000);
			MS5611_Reset(&baro);
			berrors++;
			pressure = realPressureAv;
			if (berrors > 100) { //give it up
				pressure = baro.uP;
			}

		}

	} else {

		pressure = baro.uP;
	}

	return pressure;

}

//This is called at about 30ms
void Baro_Read() {

	count++; //Debug counter.
	MS5611_readPressure(&baro1);
	int32_t pressure = getCleanValues(baro1);

#if defined(VARIO2)
	MS5611_readPressure(&baro2);
	int32_t pressure2 = getCleanValues(baro2);
	int32_t pressure1t;
	int32_t pressure2t;

#if defined(VARIO2LEASTDEV)
	int32_t diff = rawPressurePrev - pressure;
	int32_t diff2 = rawPressurePrev2 - pressure2;

	//alter the sensor reading
	//This method is to filter electrical noise
	if (fabs(diff) > fabs(diff2)) { //if the primary has more deviation use the deviation of the secondary sensor
		pressure1t = rawPressurePrev + diff2;
		pressure2t = pressure2;

	} else {
		pressure2t = rawPressurePrev2 + diff;
		pressure1t = pressure;
	}
	rawPressurePrev = pressure;
	rawPressurePrev2 = pressure2;
	pressure = (pressure1t + pressure2t) / 2;

#else

	pressure = (pressure + pressure2) / 2;

#endif
#endif

	  realPressureAv = (conf.variosmooth * realPressureAv + pressure) / (conf.variosmooth + 1);

	}

void checkAdaptiveVario(float vario) {
#if defined(ADAPTIVEVARIO)

  double triggerLevel = (double)(conf.advTriggerLevel)/1000;

  if(takeoff) { //compensate for glider sink
    vario += -(double)(conf.gliderSinkRate)/1000;
  }


  if (fabs(vario) > triggerLevel && !vTriggerd) { //fabs abs but can handle floats
	vtime = HAL_GetTick();
    vTriggerd = true;
  }

  int diff = HAL_GetTick() - vtime;

  //Vario level goes back to zero within TriggerTime, increase the filter
  if (vTriggerd && fabs(vario) < triggerLevel  && diff < (int)(conf.advTriggerTime))  {
    if (conf.variosmooth <= conf.advMaxSmooth ) {
      conf.variosmooth++;
      vTriggerd = false;
      vtime = HAL_GetTick();

    }
  }

  //overflow reset
  if (diff > conf.advTriggerTime && vTriggerd) {
    vTriggerd = false;
    vtime = HAL_GetTick();;
  }
  //Vario stays below trigger level for advRelaxTime, decrease the filter
  if (fabs(vario) < (float)(triggerLevel) && !vTriggerd && diff >  conf.advRelaxTime) {
    if (conf.variosmooth > conf.advMinSmooth ) {
      conf.variosmooth--;
      vtime = HAL_GetTick();
    }
  }
#endif
}

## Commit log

2017-10-22 Added all devices
2017-10-23 removed timer function from DHT
2017-11-03 Eagle Files
    [FreeVario F101 V1.1.brd, FreeVario F101 V1.1.sch]
2017-12-17 Added bill of material
    [bom.ods]
2018-02-10 Added HAL timers and buzzer
    [FreeVario.ioc, audio.c, config_hal.h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]
2018-03-03 Switched to main branche
2018-03-04 Added IWGD. Improved ms5611 i2C connectivity.
2018-03-05 Added I2C helper in place of weird value watchdog
2018-03-05 Added bus reset to baro value overload
    [barosensor.c, freevario.c, i2chelper.c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]
2018-03-08 Improved stability. Buffer overrun prevention.
    [FreeVario.ioc, config_hal.h, freevario.c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]
2018-03-11 Imroved I2C stability
2018-03-13 Started with buttons
2018-03-14 Added prev next button. 1st milestone reached.
2018-03-18 Added Extra board
2018-03-28 Fixed c-probe NMEA sentence
    [am2322.c, audio.c, config_hal.h]
2018-03-30 Moved internal io to seperate file. Added powerbank function.
2018-03-31 Added interval powerbank option. Most devices probably won't support it.
    [audio.c, boardgpio.c, config.h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]
2018-04-01 Added battery %
2018-04-01 Fixed NMEA sentence battery %
    [boardgpio.c, freevario.c]
2018-04-01 Added STM32F302
2018-04-02 Small correction for the mpu6050 adress pin
    [FreeVario F101 V1.2.brd, FreeVario F101 V1.2.sch]
2018-04-02 Added low pass filter
2018-05-27 Added option to disable powerbank function at startup
2018-06-09 Added power save function for the OLED screen

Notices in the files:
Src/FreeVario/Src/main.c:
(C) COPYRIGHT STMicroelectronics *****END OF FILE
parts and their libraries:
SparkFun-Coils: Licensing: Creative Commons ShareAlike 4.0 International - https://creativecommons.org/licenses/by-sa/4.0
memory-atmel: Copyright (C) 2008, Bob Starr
